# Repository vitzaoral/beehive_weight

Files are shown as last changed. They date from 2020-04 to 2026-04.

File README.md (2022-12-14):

# Bee hive weight monitoring with ESP8266 or ESP32
Bee hive weight monitoring. 
Based on [Bodge HX711 library](https://github.com/bogde/HX711).
Data are sent to the Blynk.

## 🚀 12.2022 - UPDATE TO BLYNK 2.0 🚀
Project was updated to the new version of [Blynk 2.0](https://docs.blynk.io/en/)

> To build a project, you need to download all the necessary libraries and create the *settings.cpp* file in the *src* folder:
```c++
// Project settings
struct Settings
{
    const char *wifiSSID = "wifi";
    const char *wifiPassword = "pswd";
    const char *blynkAuth = "blynkAuth"; // for each weight
    const char *version = "1.0.0";
    const double scale = 22500; // for each weight
    const double offset = 0.9; // for each weight
};
```
### Features
* measuring the weight of the beehive
* Sends push notification, when weight decrease between measuring is lower than 1Kg (detection of bee swarm)

### Currents list:

* *ESP32 WROOM-32* or *WEMOS D1 Mini*
* [HX711](https://www.aliexpress.com/wholesale?SearchText=hx711)
* *Sencor SBS 113SL* or some other load cells

### In development 🚧
You should consider getting into the details of strain-gauge load cell sensors when expecting reasonable results. The range of topics is from sufficient and stable power supply, using the proper excitation voltage to the Seebeck effect and temperature compensation. See also [Bodge HX711 library](https://github.com/bogde/HX711).

### Schema:
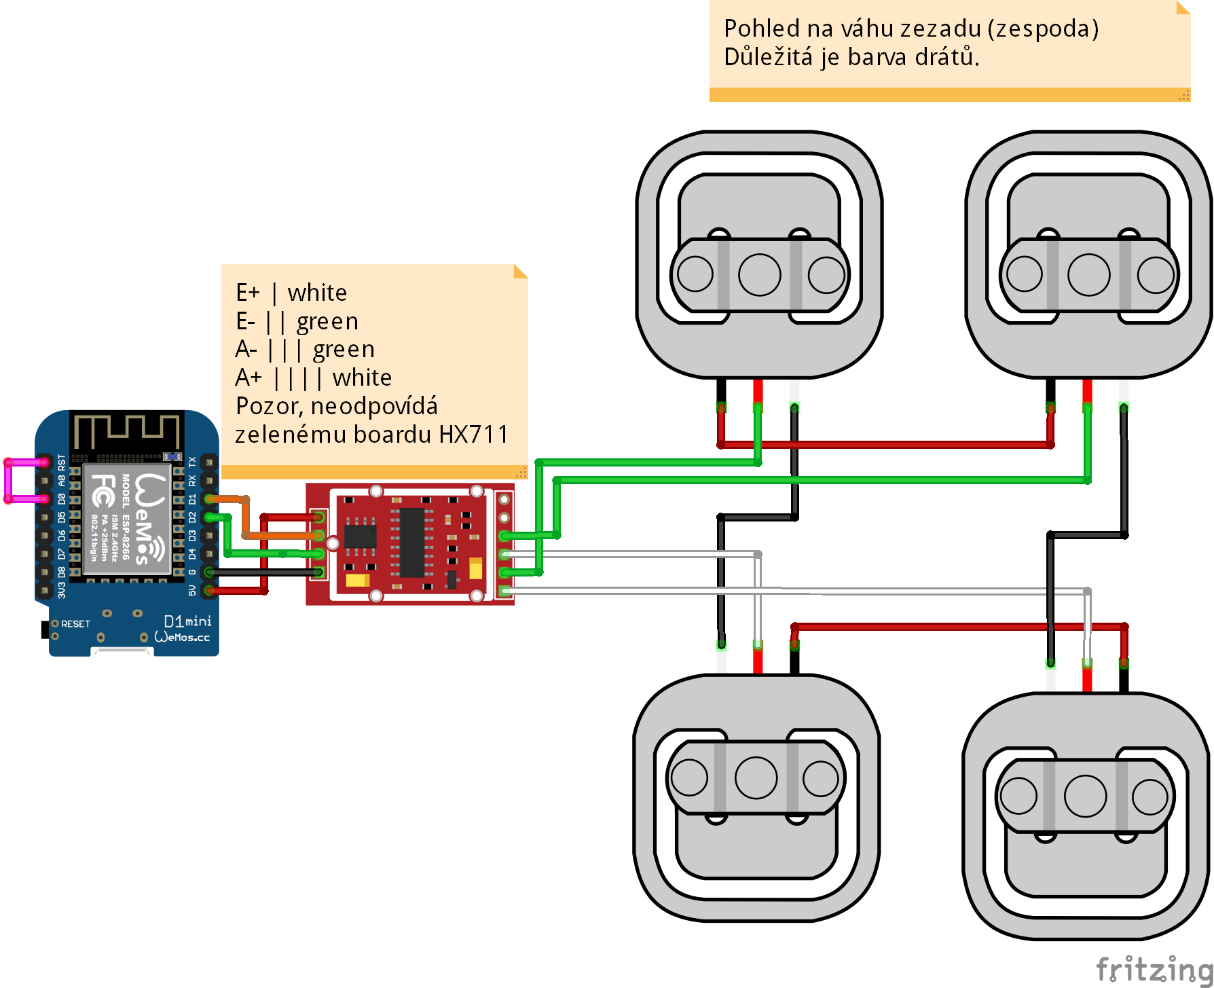
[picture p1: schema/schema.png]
Schema


### Blynk:
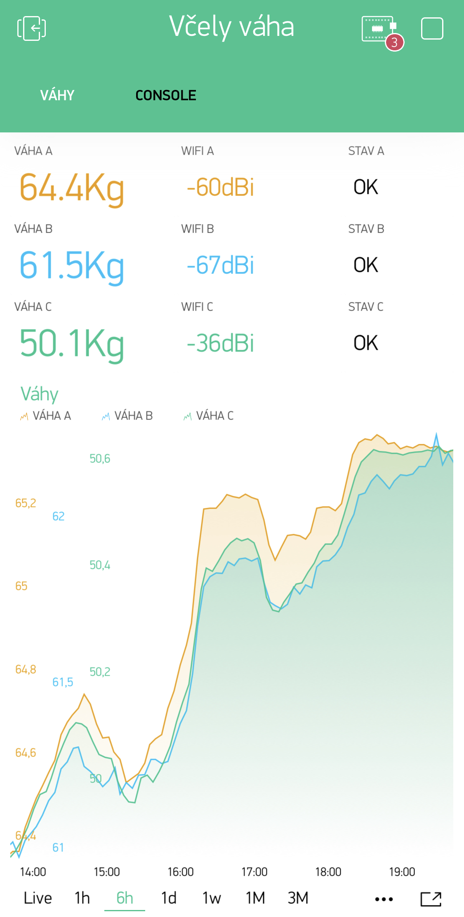
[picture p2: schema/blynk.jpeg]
Schema


### Outside:
Schema
Schema
Schema

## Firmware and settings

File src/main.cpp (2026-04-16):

#define BLYNK_PRINT Serial
#define BLYNK_TEMPLATE_ID "TMPLkxFvg8yn"
#define BLYNK_TEMPLATE_NAME "Váhy včel"
#define BLYNK_FIRMWARE_VERSION "2.1.0"

#include <Arduino.h>
#include "HX711.h"
#include <ESP8266WiFi.h>
#include <ESP8266HTTPClient.h>
#include <ESP8266httpUpdate.h>
#include <BlynkSimpleEsp8266.h>
#include <EEPROM.h>
extern "C" {
  #include <user_interface.h>
}
#include "../src/settings.cpp"

// https://github.com/bogde/HX711

// zapojeni https://cdn.instructables.com/F36/2JAR/J822Y1NX/F362JARJ822Y1NX.LARGE.jpg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
// bacha na barevnost dratu, hlavni je prostredni ze senzoru

// TODO: zavislost na teplote
// zima "zvysuje vahu", teplo snizuje. Pri 20C vaha 14.1kg, pri 3C vaha 14.5kg
// https://community.hiveeyes.org/t/temperature-compensation-for-hx711-and-or-load-cell/1601/4

// HX711 circuit wiring
const int LOADCELL_DOUT_PIN = D1;
const int LOADCELL_SCK_PIN = D2;

// about 5 minutes 293e6
// about 20 minutes 1193e6
// const double DEEP_SLEEP_TIME = 293e6;

// Deep sleep interval in seconds
int deep_sleep_interval = 285;

Settings settings;
HX711 scale;

BLYNK_WRITE(InternalPinOTA)
{
  Serial.println("OTA Started");
  String otaUrl = param.asString();
  Serial.print("overTheAirURL = ");
  Serial.println(otaUrl);

  WiFiClient otaClient;
  t_httpUpdate_return ret = ESPhttpUpdate.update(otaClient, otaUrl);
  switch (ret)
  {
  case HTTP_UPDATE_FAILED:
    Serial.println("[update] Update failed.");
    break;
  case HTTP_UPDATE_NO_UPDATES:
    Serial.println("[update] Update no Update.");
    break;
  case HTTP_UPDATE_OK:
    Serial.println("[update] Update ok."); // may not be called since we reboot the ESP
    break;
  }
}

// deep sleep interval in seconds
BLYNK_WRITE(V8)
{
  if (param.asInt())
  {
    deep_sleep_interval = param.asInt();
    Serial.println("Deep sleep interval was set to: " + String(deep_sleep_interval));
    Blynk.virtualWrite(V7, String(deep_sleep_interval));
  }
}

// Synchronize settings from Blynk server with device when internet is connected
BLYNK_CONNECTED()
{
  Blynk.syncVirtual(V0, V8);
}

// device is enabled
bool isEnabled = true;

// Turn on/off
BLYNK_WRITE(V0)
{
  isEnabled = param.asInt();
}


void setup()
{
  Serial.begin(115200);
  Serial.println("Initializing the scale");

  EEPROM.begin(512);

  // Rucne zkontrolovat jestli HX711 je pripojene pred volanim begin(),
  // protoze begin() vola set_gain() -> read() -> wait_ready() coz je
  // nekonecny loop a zpusobi WDT reset kdyz HX711 neni zapojene
  pinMode(LOADCELL_DOUT_PIN, INPUT);
  pinMode(LOADCELL_SCK_PIN, OUTPUT);
  digitalWrite(LOADCELL_SCK_PIN, LOW);
  delay(500);

  bool hx711Present = false;
  unsigned long startMs = millis();
  while (millis() - startMs < 3000)
  {
    if (digitalRead(LOADCELL_DOUT_PIN) == LOW)
    {
      hx711Present = true;
      break;
    }
    delay(10);
  }

  bool secondChance = false;
  bool scaleReady = false;

  if (hx711Present)
  {
    scale.begin(LOADCELL_DOUT_PIN, LOADCELL_SCK_PIN);
    delay(300);
    scale.power_up();
    delay(1000);
    scaleReady = scale.wait_ready_timeout(3000);

    if (!scaleReady)
    {
      secondChance = true;
      scale.power_down();
      delay(1000);
      scale.begin(LOADCELL_DOUT_PIN, LOADCELL_SCK_PIN);
      delay(300);
      scale.power_up();
      delay(1000);
      yield();
      scaleReady = scale.wait_ready_timeout(3000);
    }
  }
  else
  {
    Serial.println("HX711 neni pripojene");
  }

  if (scaleReady)
  {
    // Sencor SBS 113L
    scale.set_scale(settings.scale);
    delay(1000);
    yield();

    // formula A. B. C
    // cte po jednom s yield() aby WDT neresetoval ESP
    float sum = 0;
    int validReadings = 0;
    for (int i = 0; i < 10; i++)
    {
      if (scale.wait_ready_timeout(1000))
      {
        sum += scale.get_units(1);
        validReadings++;
      }
      yield();
    }

    float average = (validReadings > 0) ? (sum / validReadings) : 0;
    if (average < 0)
    {
      average = average * -1;
    }

    float value = average + settings.offset;

    // // formula E, F
    // float value = scale.get_units(10) + settings.offset;
    // if (value < 0)
    // {
    //   value = value * -1;
    // }

    Serial.println("average:\t" + String(value) + " kg");

    int connAttempts = 0;
    Serial.println("\r\nTry connecting to: " + String(settings.wifiSSID));

    WiFi.begin(settings.wifiSSID, settings.wifiPassword);

    while (WiFi.status() != WL_CONNECTED)
    {
      delay(500);
      Serial.print(".");
      if (connAttempts > 30)
      {
        Serial.println("Error - couldn't connect to WIFI");
        break;
      }

      connAttempts++;
    }

    Blynk.config(settings.blynkAuth);
    Blynk.connect(2000);

    if (Blynk.connected())
    {
      Serial.println("WiFI connected OK");
    }
    else
    {
      Serial.println("No WIFI !");
    }

    // wait for blynk sync
    delay(1000);

    Blynk.virtualWrite(V2, WiFi.RSSI());
    Blynk.virtualWrite(V4, settings.version);
    Blynk.virtualWrite(V5, isEnabled ? (secondChance ? "OK 2 pokusy" : "OK") : "Váha je vypnuta.");

    if (isEnabled)
    {
      Serial.println("ENABLED");
      Blynk.virtualWrite(V1, value);

      float previousValue = 0.00f;
      EEPROM.get(0, previousValue);
      EEPROM.put(0, value);
      EEPROM.commit();

      // validace EEPROM - pri prvnim spusteni nebo poskozenych datech
      bool validPrevious = !isnan(previousValue) && !isinf(previousValue) && previousValue > 0 && previousValue < 200;

      if (validPrevious)
      {
        float difference = value - previousValue;
        Blynk.virtualWrite(V6, difference);

        // detekce rojeni - pokles vahy o vice nez 1 kg
        if (difference < -1.0)
        {
          Blynk.logEvent("swarm_detected", String("Pokles váhy o ") + String(difference, 1) + " kg");
        }
      }
      else
      {
        Blynk.virtualWrite(V6, 0);
      }
    } else {
      Serial.println("DISABLED");
    }

    if (Blynk.connected())
    {
      Serial.println("Sent OK");
    }
  }
  else
  {
    Serial.println("HX711 doesn't work");

    // Pouzit lehci WiFi.begin + Blynk.config misto tezkeho Blynk.begin
    WiFi.begin(settings.wifiSSID, settings.wifiPassword);
    int connAttempts = 0;
    while (WiFi.status() != WL_CONNECTED)
    {
      delay(500);
      if (connAttempts > 30) break;
      connAttempts++;
    }
    Blynk.config(settings.blynkAuth);
    Blynk.connect(2000);

    Serial.println("Connect blynk");

    int rssi = WiFi.RSSI();
    Blynk.virtualWrite(V2, rssi);
    Blynk.virtualWrite(V4, settings.version);

    if (secondChance)
    {
      Blynk.virtualWrite(V5, "HX711 nefunguje. 2. pokus");
    }
    else
    {
      Blynk.virtualWrite(V5, "HX711 nefunguje.");
    }

    Serial.println("Blynk send");
  }

  scale.power_down();
  delay(300);

  if (WiFi.isConnected())
  {
    Blynk.disconnect();
    WiFi.disconnect(true);

    Serial.println("Disconnected OK");
  }
  else
  {
    Serial.println("Already disconnected");
  }

  EEPROM.end();

  Serial.println("Go to sleep for " + String(deep_sleep_interval) + " seconds.");
  system_deep_sleep_instant(deep_sleep_interval * 1000000UL);
}

void loop()
{
}

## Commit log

2020-04-08 Schema, pins
    [schema.fzz]
2020-04-10 A, B, and C load calibrations
2020-04-27 When HX711 doesn't work, connect to Blynk and send message
    [main.cpp]
2020-05-30 Enable/disable device with Blynk
2026-04-16 Fix WDT reset and stack smashing crashes
    - Check HX711 presence before calling begin() which has infinite wait loop
    - Remove WidgetTerminal and global WiFiClient to reduce RAM usage
    - Replace Blynk.begin() with lighter WiFi.begin + Blynk.config pattern
    - Use system_deep_sleep_instant() to avoid stack canary check crash
    - Add EEPROM validation and swarm detection via weight drop
    - Replace syncAll() with syncVirtual(V0, V8) for lower stack usage
    - Read HX711 one sample at a time with yield() between reads
    [main.cpp]
